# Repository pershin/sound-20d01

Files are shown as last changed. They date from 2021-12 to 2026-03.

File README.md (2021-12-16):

# Sound-20D01

## Sound-20D01MB

### Bill of Materials

| Reference | Value | Package | Qnty |
|:---:| --- | --- |:----:|
| C1, C2, C3, C4, C5, C10, C12, C13, C14, C16, C22, C25, C26, C28, C30, C42, C54 | 0.1uF, X7R, 50V | 1206 | 17 |
| C6, C7 | 15pF, C0G (NP0), 50V | 1206 | 2 |
| C8, C9 | 22pF, C0G (NP0), 50V | 1206 | 2 |
| C11, C41 | 1uF, X7R, 50V | 1206 | 2 |
| C15 | 4.7uF, X7R, 50V | 1206 | 1 |
| C18, C23 | 2.2nF, B32529C8222J000 | 2.5 x 6.5 x 7.3 | 2 |
| C19, C20, C33, C37, C40, C46, C47, C50, C51 | 2.2uF, X7R, 50V | 1206 | 9 |
| C21, C24, C45, C48, C49, C55, C17, C27 | 10uF, 16V | SMD 4 x 5.4 | 8 |
| C29, C43 | 470uF, 63V, B41851F8477M000 | 12.5 x 20 | 2 |
| C31 | 10uF, X7R, 50V | 1210 | 1 |
| C32, C39 | 4700uF, 35V | 18 x 35.5 | 2 |
| C34, C38 | 0.68uF | 7.2 x 4.5 mm | 2 |
| C35, C36 | 0.22uF, X7R, 50V | 1206 | 2 |
| C44 | 47uF, 16V | SMD 6.3 x 5.4 | 1 |
| C52 | 47uF, 50V | SMD 6.3 x 7.7 | 1 |
| C53 | 0.33uF, X7R, 50V | 1206 | 1 |
| D1, D4, D5 | KP-3216MGC (Green) | 1206 | 3 |
| D2 | KP-3216SEC (Orange) | 1206 | 1 |
| D3 | CRS04 | SOD-123F | 1 |
| F1 | MF-MSMF050-2 | 1812 (4532) | 1 |
| J1 | USBB-1J | USB-B1HSxx | 1 |
| J2 | X977B04 | 7.62 mm | 1 |
| J3 | PLD-16 | 2.54 mm | 1 |
| J4 | PLD-8 | 2.54 mm | 1 |
| J5, J13 | PLS-6 | 2.54 mm | 2 |
| J6, J7 | PLD-20 | 2.54 mm | 2 |
| J8, J9 | JST XH B02B-XH-A | 2.50 mm | 2 |
| J10 | JST VH B2P-VH | 3.96 mm | 1 |
| J11, J14, JP1, JP2 | PLS-3 | 2.54 mm | 4 |
| J12 | PLS-4 | 2.54 mm | 1 |
| L1, L2 | 22uH | Bourns SRR1260 | 2 |
| R1, R10, R17, R18, R22, R24 | 10K, 1% | 1206 | 6 |
| R2, R3, R15, R16 | 4.7K, 1% | 1206 | 4 |
| R4, R5, R8, R11, R12, R14 | 22R, 1% | 1206 | 6 |
| R6 | 390R, 1% | 1206 | 1 |
| R7 | 51R, 1% | 1206 | 1 |
| R9, R13 | 470R, 1% | 1206 | 2 |
| R19, R20, R21, R23, R26 | 1K, 1% | 1206 | 5 |
| R25 | 680R, 1% | 1206 | 1 |
| SW1 | DS1040-02RN | DIP SPSTx02 | 1 |
| U1 | USBLC6-2SC6 | SOT23-6L | 1 |
| U2 | STM32F446RCT6 | LQFP-64 | 1 |
| U3 | PCM5142PW | TSSOP-28 | 1 |
| U4 | TPA3123D2PWP | HTSSOP-24 (PWP0024B) | 1 |
| U5, U6 | FOD817B | DIP-4 7.62mm | 2 |
| U7, U8 | ADP3338AKCZ-3.3RL7 | SOT-223 | 2 |
| U9 | L7805ABD2T-TR | D2PAK (TO-263) | 1 |
| X1 | SM7745HEV-12.288M | 5 x 7 mm LCC Ceramic Package | 1 |
| Y1 | 32.768kHz (FC-135) | SMD 3215 | 1 |
| Y2 | 8MHz (AT-41CD2) | SMD HC49-SM | 1 |

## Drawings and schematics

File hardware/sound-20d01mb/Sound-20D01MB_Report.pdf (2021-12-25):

## Общий отчет о проекте

# Наименование: Sound-20D01MB

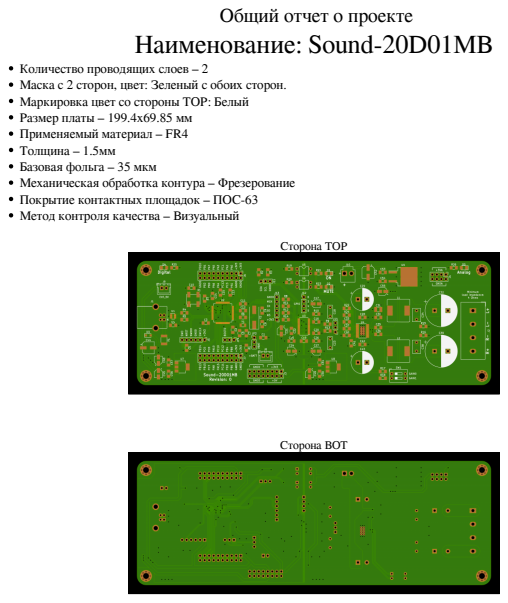
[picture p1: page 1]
Сторона TOP; Сторона BOT

Количество проводящих слоев – 2
Маска с 2 сторон, цвет: Зеленый с обоих сторон.
Маркировка цвет со стороны TOP: Белый
Размер платы – 199.4х69.85 мм
Применяемый материал – FR4
Толщина – 1.5мм
Базовая фольга – 35 мкм
Механическая обработка контура – Фрезерование
Покрытие контактных площадок – ПОС-63
Метод контроля качества – Визуальный

Powered by TCPDF (www.tcpdf.org)

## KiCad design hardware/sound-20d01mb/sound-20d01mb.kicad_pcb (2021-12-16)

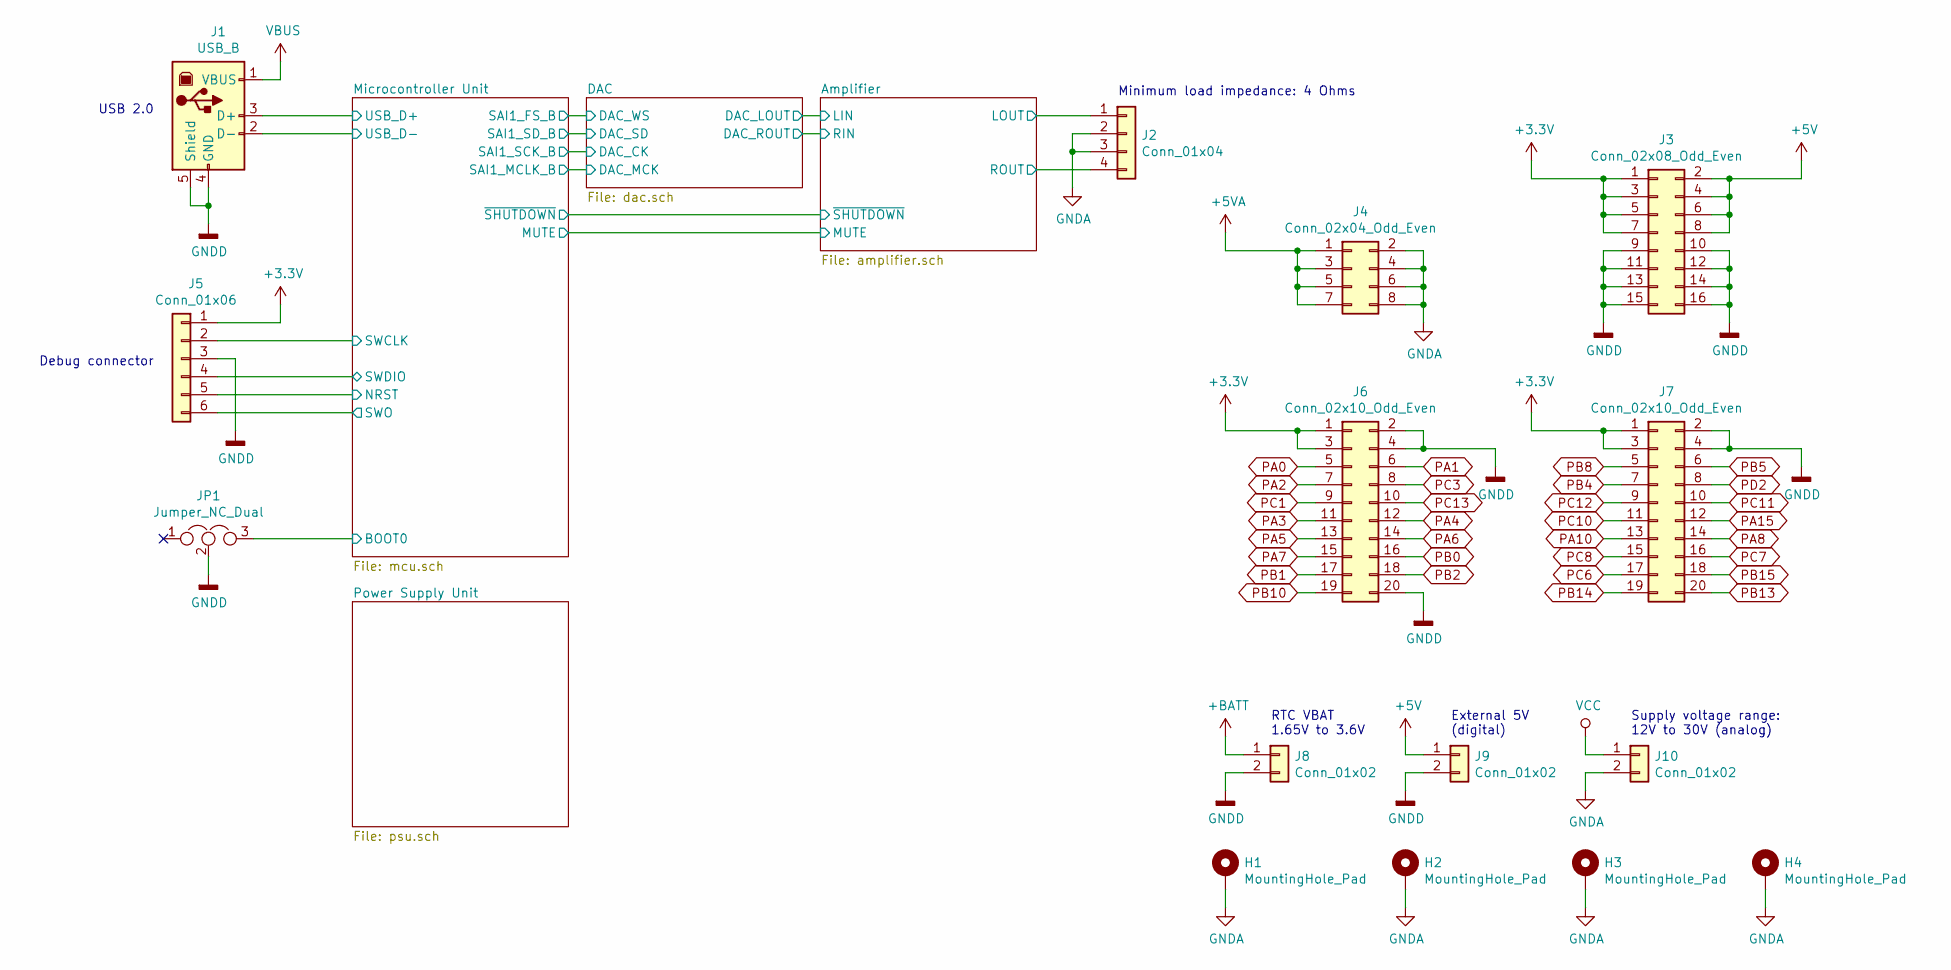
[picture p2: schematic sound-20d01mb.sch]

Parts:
H1, H2, H3, H4: MountingHole_Pad; MountingHole_3.2mm_M3_Pad_Via
J1: USB_B; USB_B_OST_USB-B1HSxx_Horizontal
J2: Conn_01x04; X977B04
J3: Conn_02x08_Odd_Even; PinHeader_2x08_P2.54mm_Vertical
J4: Conn_02x04_Odd_Even; PinHeader_2x04_P2.54mm_Vertical
J5: Conn_01x06; PinHeader_1x06_P2.54mm_Vertical
J6, J7: Conn_02x10_Odd_Even; PinHeader_2x10_P2.54mm_Vertical
J8, J9: Conn_01x02; JST_XH_B02B-XH-A_1x02_P2.50mm_Vertical
J10: Conn_01x02; JST_VH_B2P-VH_1x02_P3.96mm_Vertical
JP1: Jumper_NC_Dual; PinHeader_1x03_P2.54mm_Vertical

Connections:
+5V: J3.2, J3.4, J3.6, J3.8, J9.1; also elsewhere on the board
+5VA: J4.1, J4.3, J4.5, J4.7; also elsewhere on the board
+BATT: J8.1; also elsewhere on the board
/Amplifier/LOUT: J2.1; also elsewhere on the board
/Amplifier/ROUT: J2.4; also elsewhere on the board
/Microcontroller Unit/BOOT0: JP1.3; also elsewhere on the board
/Microcontroller Unit/NRST: J5.5; also elsewhere on the board
/Microcontroller Unit/SWCLK: J5.2; also elsewhere on the board
/Microcontroller Unit/SWDIO: J5.4; also elsewhere on the board
/Microcontroller Unit/SWO: J5.6; also elsewhere on the board
/Microcontroller Unit/USB_D+: J1.3 (D+); also elsewhere on the board
/Microcontroller Unit/USB_D-: J1.2 (D-); also elsewhere on the board
GNDA: H1.1, H2.1, H3.1, H4.1, J2.2, J2.3, J4.2, J4.4, J4.6, J4.8, J10.2; also elsewhere on the board
GNDD: J1.4 (GND), J1.5 (Shield), J3.9, J3.10, J3.11, J3.12, J3.13, J3.14, J3.15, J3.16, J5.3, J6.2, J6.4, J6.20, J7.2, J7.4, J8.2, J9.2, JP1.2; also elsewhere on the board
PA0: J6.5; also elsewhere on the board
PA1: J6.6; also elsewhere on the board
PA2: J6.7; also elsewhere on the board
PA3: J6.11; also elsewhere on the board
PA4: J6.12; also elsewhere on the board
PA5: J6.13; also elsewhere on the board
PA6: J6.14; also elsewhere on the board
PA7: J6.15; also elsewhere on the board
PA8: J7.14; also elsewhere on the board
PA10: J7.13; also elsewhere on the board
PA15: J7.12; also elsewhere on the board
PB0: J6.16; also elsewhere on the board
PB1: J6.17; also elsewhere on the board
PB2: J6.18; also elsewhere on the board
PB4: J7.7; also elsewhere on the board
PB5: J7.6; also elsewhere on the board
PB8: J7.5; also elsewhere on the board
PB10: J6.19; also elsewhere on the board
PB13: J7.20; also elsewhere on the board
PB14: J7.19; also elsewhere on the board
PB15: J7.18; also elsewhere on the board
PC1: J6.9; also elsewhere on the board
PC3: J6.8; also elsewhere on the board
PC6: J7.17; also elsewhere on the board
PC7: J7.16; also elsewhere on the board
PC8: J7.15; also elsewhere on the board
PC10: J7.11; also elsewhere on the board
PC11: J7.10; also elsewhere on the board
PC12: J7.9; also elsewhere on the board
PC13: J6.10; also elsewhere on the board
PD2: J7.8; also elsewhere on the board
VBUS: J1.1 (VBUS); also elsewhere on the board
VCC: J10.1; also elsewhere on the board

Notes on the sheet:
Minimum load impedance: 4 Ohms
Supply voltage range: 12V to 30V (analog)
Debug connector
USB 2.0
External 5V (digital)
RTC VBAT 1.65V to 3.6V

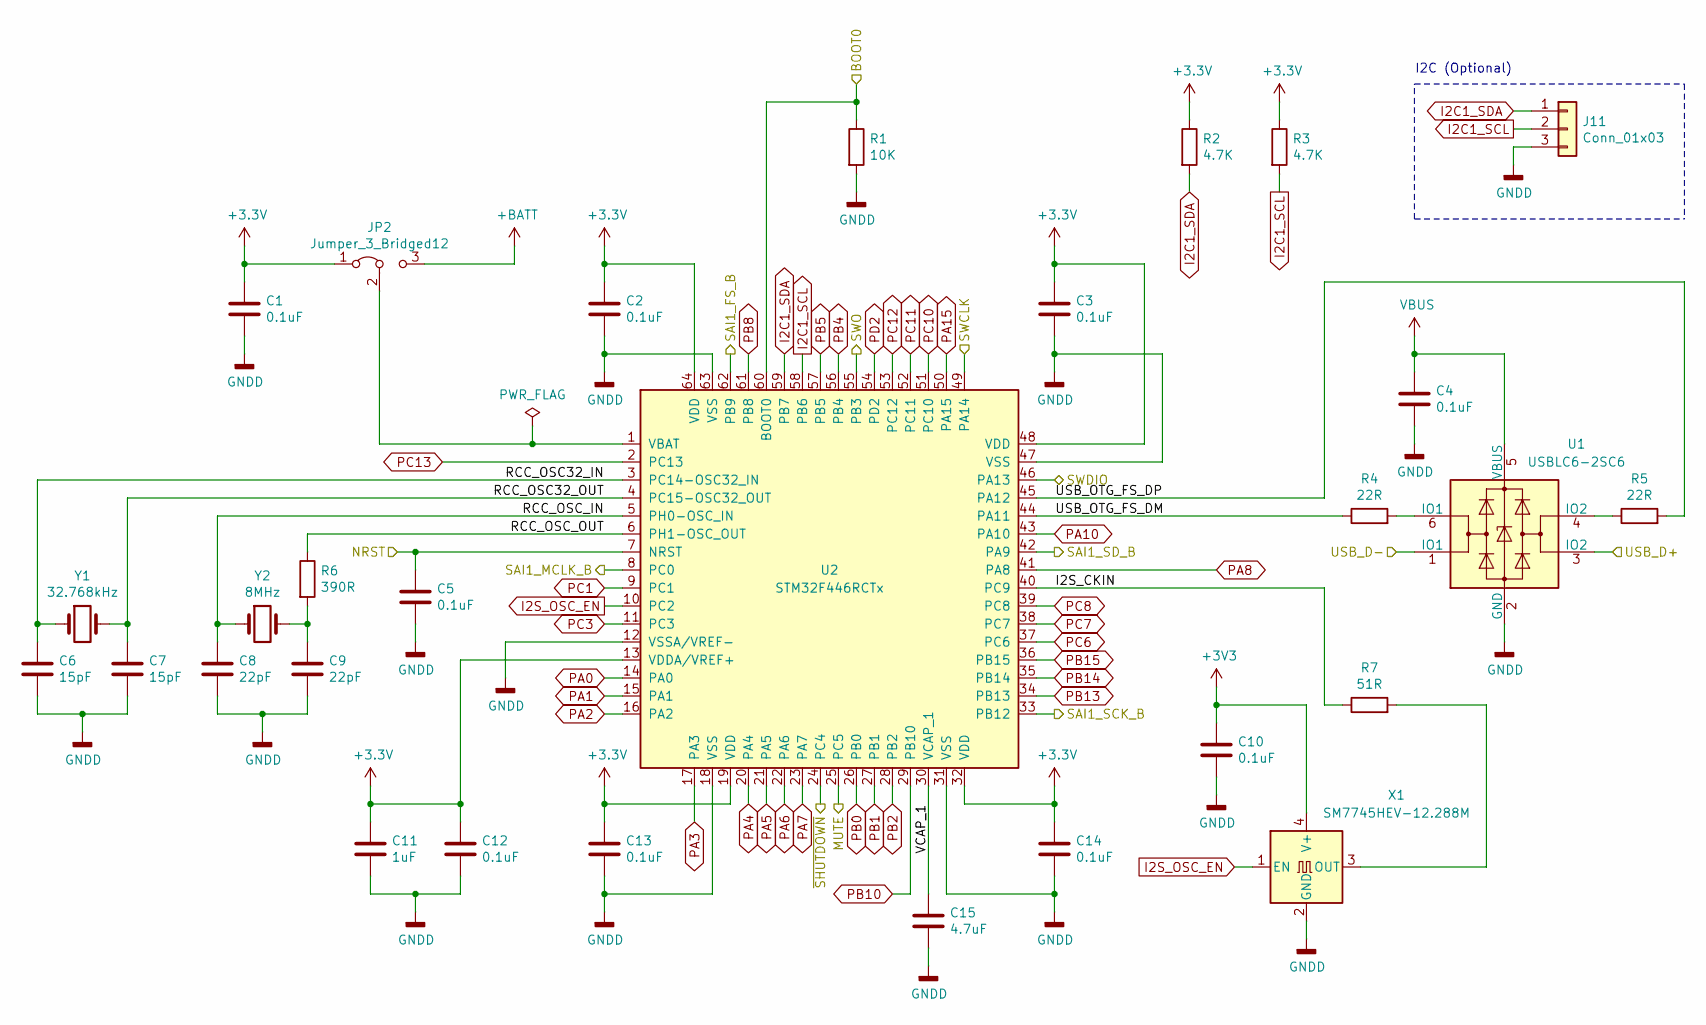
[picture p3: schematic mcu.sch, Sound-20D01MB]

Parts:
C1, C2, C3, C4, C5, C10, C12, C13, C14: 0.1uF; C_1206_3216Metric_Pad1.42x1.75mm_HandSolder
C6, C7: 15pF; C_1206_3216Metric_Pad1.42x1.75mm_HandSolder
C8, C9: 22pF; C_1206_3216Metric_Pad1.42x1.75mm_HandSolder
C11: 1uF; C_1206_3216Metric_Pad1.42x1.75mm_HandSolder
C15: 4.7uF; C_1206_3216Metric_Pad1.42x1.75mm_HandSolder
J11: Conn_01x03; PinHeader_1x03_P2.54mm_Vertical
JP2: Jumper_3_Bridged12; PinHeader_1x03_P2.54mm_Vertical
R1: 10K; R_1206_3216Metric_Pad1.42x1.75mm_HandSolder
R2, R3: 4.7K; R_1206_3216Metric_Pad1.42x1.75mm_HandSolder
R4, R5: 22R; R_1206_3216Metric_Pad1.42x1.75mm_HandSolder
R6: 390R; R_1206_3216Metric_Pad1.42x1.75mm_HandSolder
R7: 51R; R_1206_3216Metric_Pad1.42x1.75mm_HandSolder
U1: USBLC6-2SC6; SOT-23-6
U2: STM32F446RCTx; LQFP-64_10x10mm_P0.5mm
X1: SM7745HEV-12.288M; Oscillator_SMD_Fordahl_DFAS2-4Pin_7.3x5.1mm_HandSoldering
Y1: 32.768kHz; Crystal_SMD_3215-2Pin_3.2x1.5mm
Y2: 8MHz; Crystal_SMD_HC49-SD

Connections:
+BATT: JP2.3 (B); also elsewhere on the board
/Amplifier/MUTE: U2.25 (PC5); also elsewhere on the board
/Amplifier/~SHUTDOWN: U2.24 (PC4); also elsewhere on the board
/DAC/DAC_CK: U2.33 (PB12); also elsewhere on the board
/DAC/DAC_MCK: U2.8 (PC0); also elsewhere on the board
/DAC/DAC_SD: U2.42 (PA9); also elsewhere on the board
/DAC/DAC_WS: U2.62 (PB9); also elsewhere on the board
/Microcontroller Unit/BOOT0: R1.1, U2.60 (BOOT0); also elsewhere on the board
/Microcontroller Unit/I2S_CKIN: R7.1, U2.40 (PC9)
/Microcontroller Unit/NRST: C5.1, U2.7 (NRST); also elsewhere on the board
/Microcontroller Unit/RCC_OSC32_IN: C6.1, U2.3 (PC14-OSC32_IN), Y1.1
/Microcontroller Unit/RCC_OSC32_OUT: C7.1, U2.4 (PC15-OSC32_OUT), Y1.2
/Microcontroller Unit/RCC_OSC_IN: C8.1, U2.5 (PH0-OSC_IN), Y2.1
/Microcontroller Unit/RCC_OSC_OUT: R6.1, U2.6 (PH1-OSC_OUT)
/Microcontroller Unit/SWCLK: U2.49 (PA14); also elsewhere on the board
/Microcontroller Unit/SWDIO: U2.46 (PA13); also elsewhere on the board
/Microcontroller Unit/SWO: U2.55 (PB3); also elsewhere on the board
/Microcontroller Unit/USB_D+: U1.3 (IO2); also elsewhere on the board
/Microcontroller Unit/USB_D-: U1.1 (IO1); also elsewhere on the board
/Microcontroller Unit/USB_OTG_FS_DM: R4.1, U2.44 (PA11)
/Microcontroller Unit/USB_OTG_FS_DP: R5.2, U2.45 (PA12)
/Microcontroller Unit/VCAP_1: C15.1, U2.30 (VCAP_1)
GNDD: C1.2, C2.2, C3.2, C4.2, C5.2, C6.2, C7.2, C8.2, C9.2, C10.2, C11.2, C12.2, C13.2, C14.2, C15.2, J11.3, R1.2, U1.2 (GND), U2.12 (VSSA/VREF-), U2.18 (VSS), U2.31 (VSS), U2.47 (VSS), U2.63 (VSS), X1.2 (GND); also elsewhere on the board
I2C1_SCL: J11.2, R3.2, U2.58 (PB6); also elsewhere on the board
I2C1_SDA: J11.1, R2.2, U2.59 (PB7); also elsewhere on the board
I2S_OSC_EN: U2.10 (PC2), X1.1 (EN)
unnamed: C9.1, R6.2, Y2.2
unnamed: JP2.2 (C), U2.1 (VBAT)
unnamed: R4.2, U1.6 (IO1)
unnamed: R5.1, U1.4 (IO2)
unnamed: R7.2, X1.3 (OUT)
PA0: U2.14 (PA0); also elsewhere on the board
PA1: U2.15 (PA1); also elsewhere on the board
PA2: U2.16 (PA2); also elsewhere on the board
PA3: U2.17 (PA3); also elsewhere on the board
PA4: U2.20 (PA4); also elsewhere on the board
PA5: U2.21 (PA5); also elsewhere on the board
PA6: U2.22 (PA6); also elsewhere on the board
PA7: U2.23 (PA7); also elsewhere on the board
PA8: U2.41 (PA8); also elsewhere on the board
PA10: U2.43 (PA10); also elsewhere on the board
PA15: U2.50 (PA15); also elsewhere on the board
PB0: U2.26 (PB0); also elsewhere on the board
PB1: U2.27 (PB1); also elsewhere on the board
PB2: U2.28 (PB2); also elsewhere on the board
PB4: U2.56 (PB4); also elsewhere on the board
PB5: U2.57 (PB5); also elsewhere on the board
PB8: U2.61 (PB8); also elsewhere on the board
PB10: U2.29 (PB10); also elsewhere on the board
PB13: U2.34 (PB13); also elsewhere on the board
PB14: U2.35 (PB14); also elsewhere on the board
PB15: U2.36 (PB15); also elsewhere on the board
PC1: U2.9 (PC1); also elsewhere on the board
PC3: U2.11 (PC3); also elsewhere on the board
PC6: U2.37 (PC6); also elsewhere on the board
PC7: U2.38 (PC7); also elsewhere on the board
PC8: U2.39 (PC8); also elsewhere on the board
PC10: U2.51 (PC10); also elsewhere on the board
PC11: U2.52 (PC11); also elsewhere on the board
PC12: U2.53 (PC12); also elsewhere on the board
PC13: U2.2 (PC13); also elsewhere on the board
PD2: U2.54 (PD2); also elsewhere on the board
VBUS: C4.1, U1.5 (VBUS); also elsewhere on the board

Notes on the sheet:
I2C (Optional)

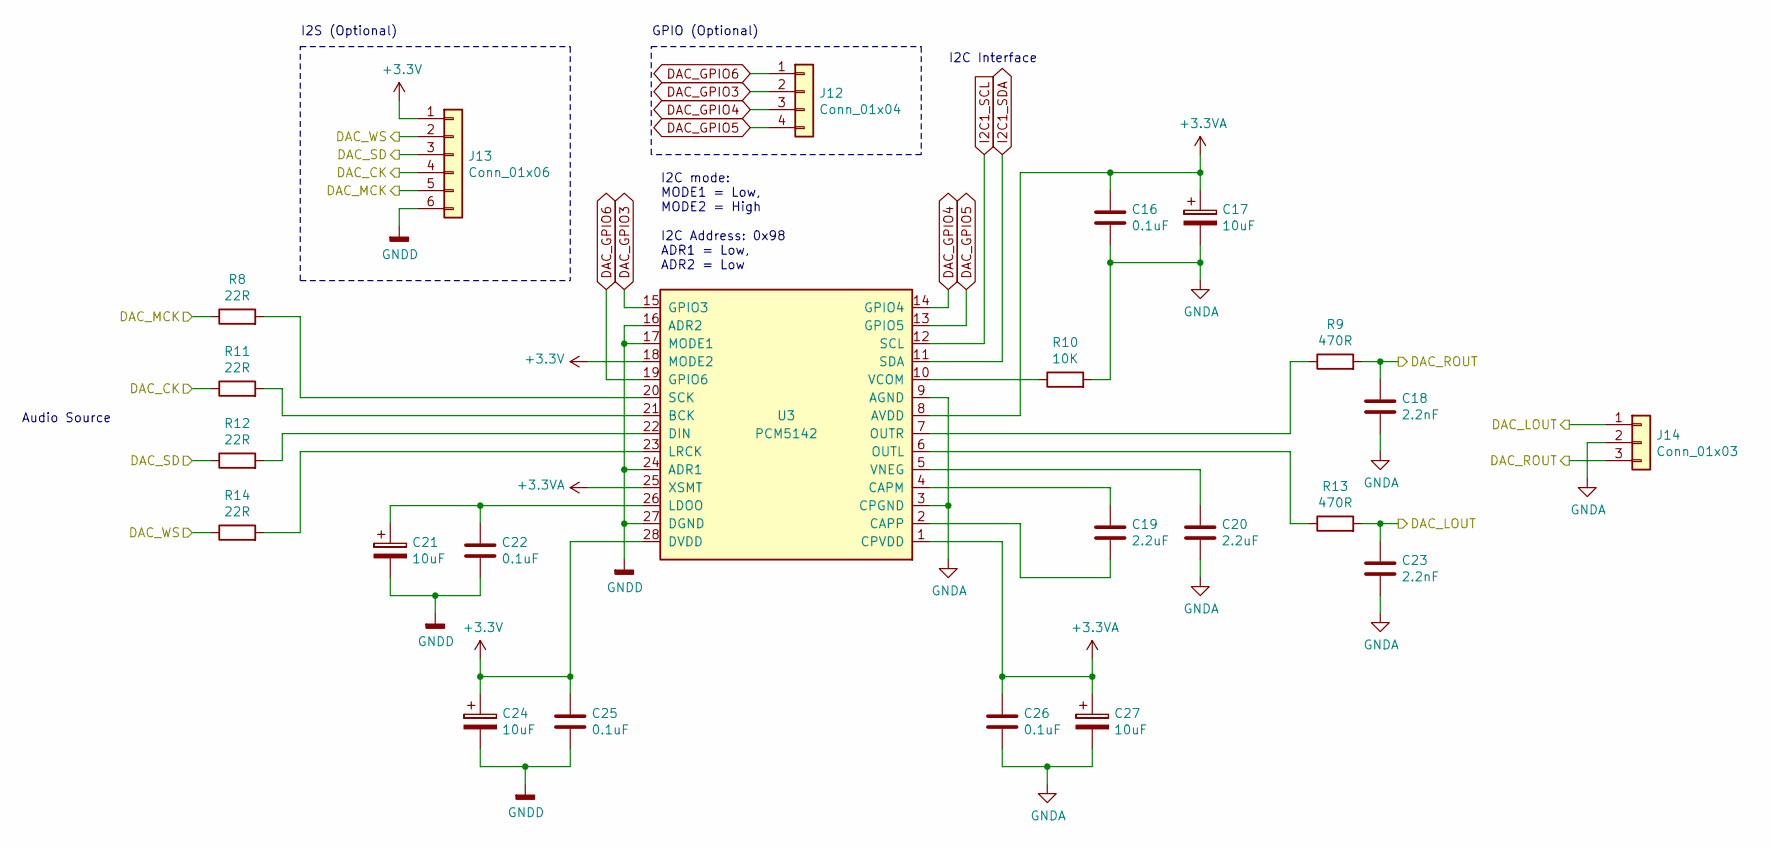
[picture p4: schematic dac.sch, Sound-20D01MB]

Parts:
C16, C22, C25, C26: 0.1uF; C_1206_3216Metric_Pad1.42x1.75mm_HandSolder
C17, C21, C24, C27: 10uF; CP_Elec_4x5.4
C18, C23: 2.2nF; C_Rect_L7.2mm_W2.5mm_P5.00mm_FKS2_FKP2_MKS2_MKP2
C19, C20: 2.2uF; C_1206_3216Metric_Pad1.42x1.75mm_HandSolder
J12: Conn_01x04; PinHeader_1x04_P2.54mm_Vertical
J13: Conn_01x06; PinHeader_1x06_P2.54mm_Vertical
J14: Conn_01x03; PinHeader_1x03_P2.54mm_Vertical
R8, R11, R12, R14: 22R; R_1206_3216Metric_Pad1.42x1.75mm_HandSolder
R9, R13: 470R; R_1206_3216Metric_Pad1.42x1.75mm_HandSolder
R10: 10K; R_1206_3216Metric_Pad1.42x1.75mm_HandSolder
U3: PCM5142; TSSOP-28_4.4x9.7mm_P0.65mm

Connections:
+3.3VA: C16.1, C17.1, C26.1, C27.1, U3.1 (CPVDD), U3.8 (AVDD), U3.25 (XSMT); also elsewhere on the board
/DAC/DAC_CK: J13.4, R11.1; also elsewhere on the board
/DAC/DAC_LOUT: C23.1, J14.1, R13.2; also elsewhere on the board
/DAC/DAC_MCK: J13.5, R8.1; also elsewhere on the board
/DAC/DAC_ROUT: C18.1, J14.3, R9.2; also elsewhere on the board
/DAC/DAC_SD: J13.3, R12.1; also elsewhere on the board
/DAC/DAC_WS: J13.2, R14.1; also elsewhere on the board
DAC_GPIO3: J12.2, U3.15 (GPIO3)
DAC_GPIO4: J12.3, U3.14 (GPIO4)
DAC_GPIO5: J12.4, U3.13 (GPIO5)
DAC_GPIO6: J12.1, U3.19 (GPIO6)
GNDA: C16.2, C17.2, C18.2, C20.2, C23.2, C26.2, C27.2, J14.2, R10.2, U3.3 (CPGND), U3.9 (AGND); also elsewhere on the board
GNDD: C21.2, C22.2, C24.2, C25.2, J13.6, U3.16 (ADR2), U3.17 (MODE1), U3.24 (ADR1), U3.27 (DGND); also elsewhere on the board
I2C1_SCL: U3.12 (SCL); also elsewhere on the board
I2C1_SDA: U3.11 (SDA); also elsewhere on the board
unnamed: C19.1, U3.4 (CAPM)
unnamed: C19.2, U3.2 (CAPP)
unnamed: C20.1, U3.5 (VNEG)
unnamed: C21.1, C22.1, U3.26 (LDOO)
unnamed: R8.2, U3.20 (SCK)
unnamed: R9.1, U3.7 (OUTR)
unnamed: R10.1, U3.10 (VCOM)
unnamed: R11.2, U3.21 (BCK)
unnamed: R12.2, U3.22 (DIN)
unnamed: R13.1, U3.6 (OUTL)
unnamed: R14.2, U3.23 (LRCK)

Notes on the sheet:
Audio Source
I2C Interface
I2C mode: MODE1 = Low, MODE2 = High I2C Address: 0x98 ADR1 = Low, ADR2 = Low
GPIO (Optional)
I2S (Optional)

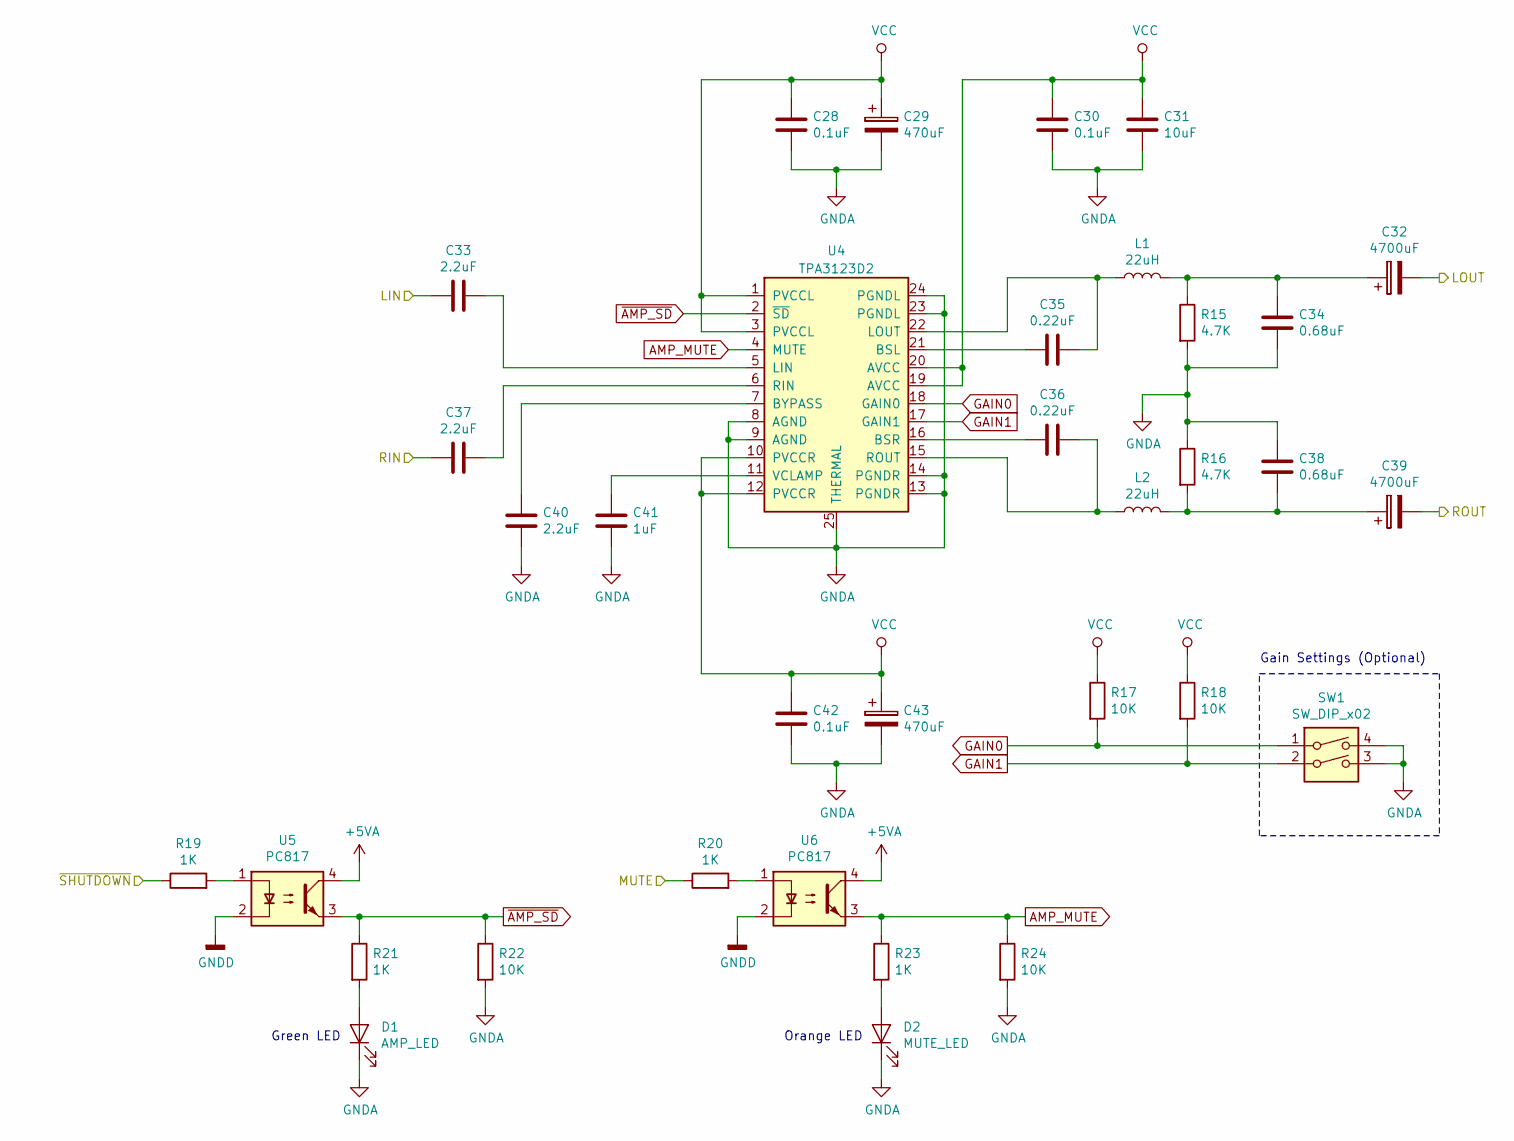
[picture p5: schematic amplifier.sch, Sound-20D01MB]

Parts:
C28, C30, C42: 0.1uF; C_1206_3216Metric_Pad1.42x1.75mm_HandSolder
C29, C43: 470uF; CP_Radial_D12.5mm_P5.00mm
C31: 10uF; C_1210_3225Metric_Pad1.42x2.65mm_HandSolder
C32, C39: 4700uF; CP_Radial_D18.0mm_P7.50mm
C33, C37, C40: 2.2uF; C_1206_3216Metric_Pad1.42x1.75mm_HandSolder
C34, C38: 0.68uF; C_Rect_L7.2mm_W4.5mm_P5.00mm_FKS2_FKP2_MKS2_MKP2
C35, C36: 0.22uF; C_1206_3216Metric_Pad1.42x1.75mm_HandSolder
C41: 1uF; C_1206_3216Metric_Pad1.42x1.75mm_HandSolder
D1: AMP_LED; LED_1206_3216Metric_Pad1.42x1.75mm_HandSolder
D2: MUTE_LED; LED_1206_3216Metric_Pad1.42x1.75mm_HandSolder
L1, L2: 22uH; L_Bourns_SRR1260
R15, R16: 4.7K; R_1206_3216Metric_Pad1.42x1.75mm_HandSolder
R17, R18, R22, R24: 10K; R_1206_3216Metric_Pad1.42x1.75mm_HandSolder
R19, R20, R21, R23: 1K; R_1206_3216Metric_Pad1.42x1.75mm_HandSolder
SW1: SW_DIP_x02; SW_DIP_SPSTx02_Slide_9.78x7.26mm_W7.62mm_P2.54mm
U4: TPA3123D2; PWP0024B
U5, U6: PC817; DIP-4_W7.62mm

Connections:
+5VA: U5.4, U6.4; also elsewhere on the board
/Amplifier/LOUT: C32.2; also elsewhere on the board
/Amplifier/MUTE: R20.1; also elsewhere on the board
/Amplifier/ROUT: C39.2; also elsewhere on the board
/Amplifier/~SHUTDOWN: R19.1; also elsewhere on the board
/DAC/DAC_LOUT: C33.1; also elsewhere on the board
/DAC/DAC_ROUT: C37.1; also elsewhere on the board
AMP_MUTE: R23.1, R24.1, U4.4 (MUTE), U6.3
GAIN0: R17.2, SW1.1, U4.18 (GAIN0)
GAIN1: R18.2, SW1.2, U4.17 (GAIN1)
GNDA: C28.2, C29.2, C30.2, C31.2, C34.2, C38.1, C40.2, C41.2, C42.2, C43.2, D1.1 (K), D2.1 (K), R15.2, R16.1, R22.2, R24.2, SW1.3, SW1.4, U4.8 (AGND), U4.9 (AGND), U4.13 (PGNDR), U4.14 (PGNDR), U4.23 (PGNDL), U4.24 (PGNDL), U4.25 (THERMAL); also elsewhere on the board
GNDD: U5.2, U6.2; also elsewhere on the board
unnamed: C32.1, C34.1, L1.2, R15.1
unnamed: C33.2, U4.5 (LIN)
unnamed: C35.1, U4.21 (BSL)
unnamed: C35.2, L1.1, U4.22 (LOUT)
unnamed: C36.1, U4.16 (BSR)
unnamed: C36.2, L2.1, U4.15 (ROUT)
unnamed: C37.2, U4.6 (RIN)
unnamed: C38.2, C39.1, L2.2, R16.2
unnamed: C40.1, U4.7 (BYPASS)
unnamed: C41.1, U4.11 (VCLAMP)
unnamed: D1.2 (A), R21.2
unnamed: D2.2 (A), R23.2
unnamed: R19.2, U5.1
unnamed: R20.2, U6.1
VCC: C28.1, C29.1, C30.1, C31.1, C42.1, C43.1, R17.1, R18.1, U4.1 (PVCCL), U4.3 (PVCCL), U4.10 (PVCCR), U4.12 (PVCCR), U4.19 (AVCC), U4.20 (AVCC); also elsewhere on the board
~AMP_SD: R21.1, R22.1, U4.2 (~SD), U5.3

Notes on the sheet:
Gain Settings (Optional)
Orange LED
Green LED

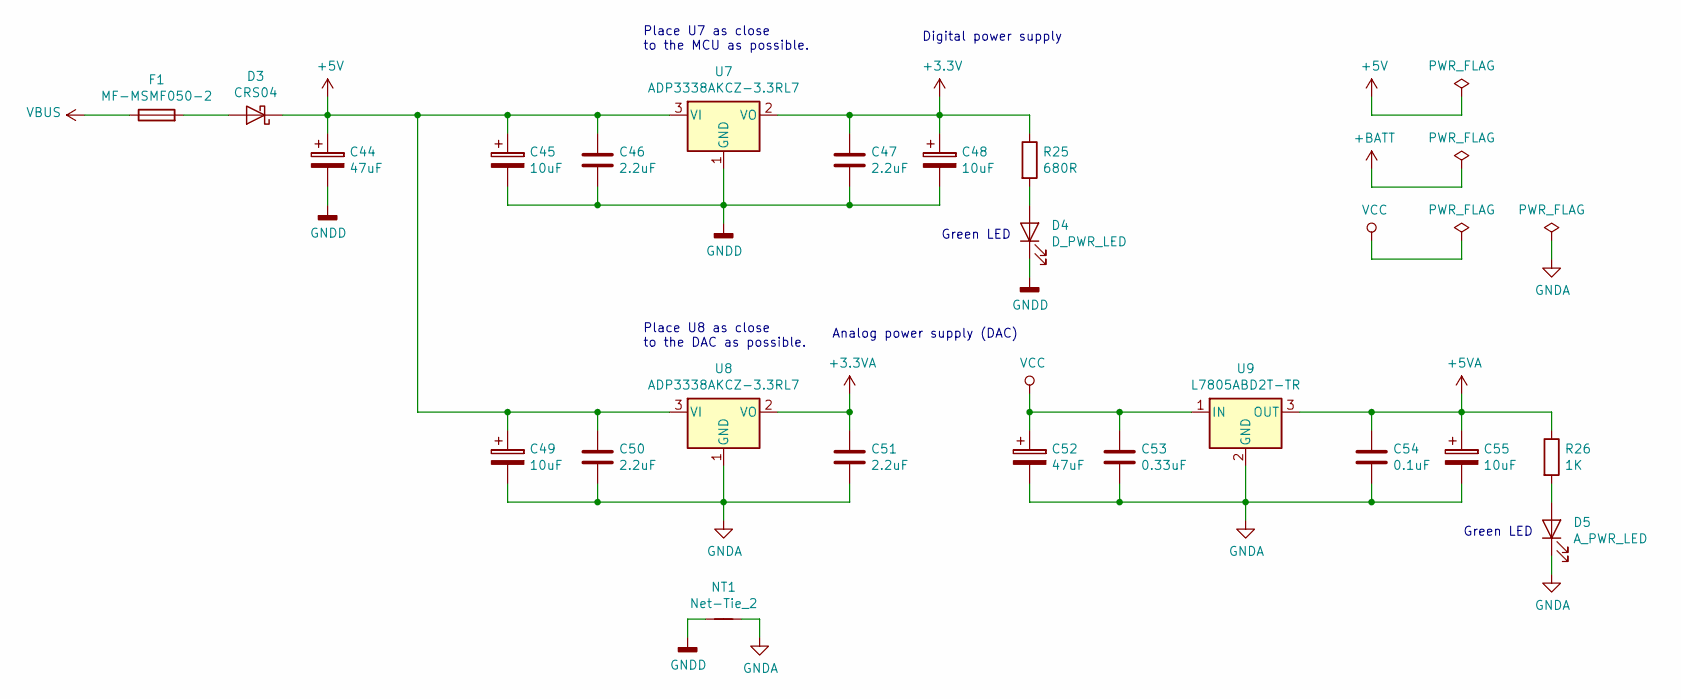
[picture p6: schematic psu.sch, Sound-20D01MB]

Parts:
C44: 47uF; CP_Elec_6.3x5.4
C45, C48, C49, C55: 10uF; CP_Elec_4x5.4
C46, C47, C50, C51: 2.2uF; C_1206_3216Metric_Pad1.42x1.75mm_HandSolder
C52: 47uF; CP_Elec_6.3x7.7
C53: 0.33uF; C_1206_3216Metric_Pad1.42x1.75mm_HandSolder
C54: 0.1uF; C_1206_3216Metric_Pad1.42x1.75mm_HandSolder
D3: CRS04; D_SOD-123F
D4: D_PWR_LED; LED_1206_3216Metric_Pad1.42x1.75mm_HandSolder
D5: A_PWR_LED; LED_1206_3216Metric_Pad1.42x1.75mm_HandSolder
F1: MF-MSMF050-2; Fuse_1812_4532Metric_Pad1.30x3.40mm_HandSolder
NT1: Net-Tie_2; NetTie-2_SMD_Pad2.0mm
R25: 680R; R_1206_3216Metric_Pad1.42x1.75mm_HandSolder
R26: 1K; R_1206_3216Metric_Pad1.42x1.75mm_HandSolder
U7, U8: ADP3338AKCZ-3.3RL7; SOT-223-3_TabPin2
U9: L7805ABD2T-TR; TO-263-2

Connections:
+3.3VA: C51.1, U8.2 (VO); also elsewhere on the board
+5V: C44.1, C45.1, C46.1, C49.1, C50.1, D3.1 (K), U7.3 (VI), U8.3 (VI); also elsewhere on the board
+5VA: C54.1, C55.1, R26.1, U9.3 (OUT); also elsewhere on the board
GNDA: C49.2, C50.2, C51.2, C52.2, C53.2, C54.2, C55.2, D5.1 (K), NT1.2, U8.1 (GND), U9.2 (GND); also elsewhere on the board
GNDD: C44.2, C45.2, C46.2, C47.2, C48.2, D4.1 (K), NT1.1, U7.1 (GND); also elsewhere on the board
unnamed: D3.2 (A), F1.2
unnamed: D4.2 (A), R25.2
unnamed: D5.2 (A), R26.2
VBUS: F1.1; also elsewhere on the board
VCC: C52.1, C53.1, U9.1 (IN); also elsewhere on the board

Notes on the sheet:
Analog power supply (DAC)
Digital power supply
Place U7 as close to the MCU as possible.
Place U8 as close to the DAC as possible.
Green LED

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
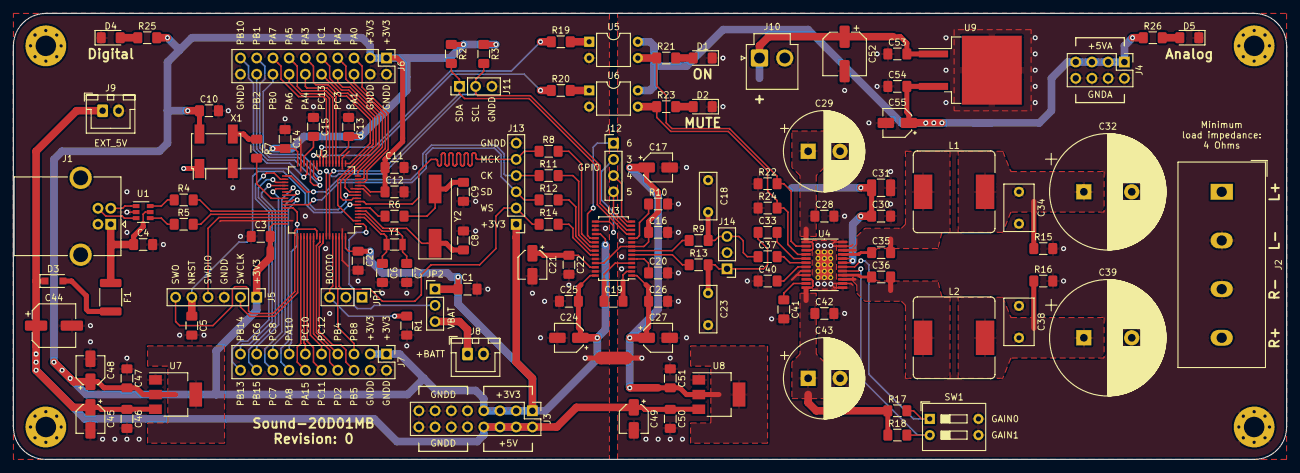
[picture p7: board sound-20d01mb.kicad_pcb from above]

Board: 2 copper layers, 199.4 x 69.8 mm, 123 parts (0 on the bottom side), 109 nets.

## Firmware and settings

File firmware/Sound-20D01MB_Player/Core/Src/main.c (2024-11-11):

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
/* Includes ------------------------------------------------------------------*/
#include "main.h"

/* USER CODE BEGIN Includes */
#include <string.h>
#include "audio.h"
#include "fs.h"
#include "display.h"
#include "playlist.h"

/* USER CODE END Includes */

/* USER CODE BEGIN PD */
#define DEFAULT_VOLUME 40
/* USER CODE END PD */

I2C_HandleTypeDef hi2c1;

SAI_HandleTypeDef hsai_BlockB1;
DMA_HandleTypeDef hdma_sai1_b;

SD_HandleTypeDef hsd;

SPI_HandleTypeDef hspi2;

/* USER CODE BEGIN PV */
volatile uint8_t read_next_chunk = 0;
volatile uint8_t *buffer_play = NULL;
volatile uint8_t *buffer_read = NULL;
uint8_t buffer_a[CLUSTER_SIZE];
uint8_t buffer_b[CLUSTER_SIZE];
volatile uint16_t numread;
volatile uint16_t cmd = 0;
volatile uint16_t track_number = 0;
volatile uint16_t old_track_number = 0;
volatile uint16_t number_of_tracks = 0;
volatile uint8_t volume = DEFAULT_VOLUME;
/* USER CODE END PV */

void SystemClock_Config(void);
static void MX_GPIO_Init(void);
static void MX_DMA_Init(void);
static void MX_SAI1_Init(void);
static void MX_I2C1_Init(void);
static void MX_SDIO_SD_Init(void);
static void MX_SPI2_Init(void);
/* USER CODE BEGIN 0 */
#ifdef DEBUG
int _write(int32_t file, uint8_t *ptr, int32_t len) {
	UNUSED(file);

	/* Implement your write code here, this is used by puts and printf for example */
	int i = 0;
	for (i = 0; i < len; i++)
		ITM_SendChar((*ptr++));
	return len;
}
#endif

int Player_Init(void) {
	BSP_AUDIO_Init(48000, volume, 0);
	BSP_Player_SetVolume(volume);
	return 0;
}

void HAL_GPIO_EXTI_Callback(uint16_t GPIO_Pin) {
	cmd = GPIO_Pin;
}

void HAL_SAI_TxCpltCallback(SAI_HandleTypeDef *hsai) {
	volatile uint8_t *temp;

	temp = buffer_play;
	buffer_play = buffer_read;
	buffer_read = temp;

	HAL_SAI_Transmit_DMA(&hsai_BlockB1, (uint8_t *) buffer_play, numread / 2);

	if (0 != track_number) {
		read_next_chunk = 1;
	}

	UNUSED(hsai);
}

void HAL_SAI_TxHalfCpltCallback(SAI_HandleTypeDef *hsai) {
	UNUSED(hsai);
}
/* USER CODE END 0 */

/**
  * @brief  The application entry point.
  * @retval int
  */
int main(void)
{
  /* MCU Configuration--------------------------------------------------------*/

  /* Reset of all peripherals, Initializes the Flash interface and the Systick. */
  HAL_Init();

  /* Configure the system clock */
  SystemClock_Config();

  /* Initialize all configured peripherals */
  MX_GPIO_Init();
  MX_DMA_Init();
  MX_SAI1_Init();
  MX_I2C1_Init();
  MX_SDIO_SD_Init();
  MX_SPI2_Init();
  /* USER CODE BEGIN 2 */
  Player_Init();

  number_of_tracks = fs_init();
  playlist_init(number_of_tracks);
  display_update(0);

  memset(buffer_a, 0, CLUSTER_SIZE);
  memset(buffer_b, 0, CLUSTER_SIZE);

  read_next_chunk = 0;
  buffer_play = buffer_a;
  buffer_read = buffer_b;
  numread = CLUSTER_SIZE;

  HAL_SAI_Transmit_DMA(&hsai_BlockB1, (uint8_t *) buffer_play, CLUSTER_SIZE / 2);

  /* USER CODE END 2 */

  /* Infinite loop */
  /* USER CODE BEGIN WHILE */
  while (1)
  {
		if (0 != cmd) {
			switch (cmd) {
				case VOL_D_Pin: /* Volume Down */
					if (0 < volume) {
						volume--;
						BSP_Player_SetVolume(volume);
					}
					break;
				case VOL_U_Pin: /* Volume Up */
					if (100 > volume) {
						volume++;
						BSP_Player_SetVolume(volume);
					}
					break;
				case PREV_Pin: /* Previous Track */
					track_number = playlist_prev();
					break;
				case NEXT_Pin: /* Next Track */
					track_number = playlist_next();
					break;
			}

			cmd = 0;
		}

		if (old_track_number != track_number) {
			old_track_number = track_number;

			display_update(track_number);

			while (1 != read_next_chunk) {}

			fs_open(track_number);
		}

		if (1 != read_next_chunk) {
			continue;
		}

		read_next_chunk = 0;

		numread = fs_read((uint8_t *) buffer_read);
		if (CLUSTER_SIZE != numread) {
			track_number = playlist_next();
		}

    /* USER CODE END WHILE */

    /* USER CODE BEGIN 3 */
  }
  /* USER CODE END 3 */
}

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


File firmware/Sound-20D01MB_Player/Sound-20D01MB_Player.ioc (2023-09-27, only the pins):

PH0-OSC_IN.Signal=RCC_OSC_IN
Mcu.UserName=STM32F446RCTx
PA6.GPIO_Label=VOL_U
PB6.Signal=I2C1_SCL
PB2.Signal=SDIO_CK
PC4.GPIO_Label=SHUTDOWN
PB7.Signal=I2C1_SDA
PB9.Signal=SAI1_FS_B
PB1.Signal=SDIO_D2
PA6.Signal=GPXTI6
PA2.GPIO_Label=PREV
PC5.Signal=GPIO_Output
PC2.GPIO_Label=I2S_OSC_EN
PA3.Signal=GPXTI3
PC11.Signal=SDIO_D3
PC8.Signal=SDIO_D0
PC4.Signal=GPIO_Output
PC2.Signal=GPIO_Output
PC0.Signal=SAI1_MCLK_B
PC14-OSC32_IN.Signal=RCC_OSC32_IN
PA0-WKUP.GPIO_Label=DISP_LATCH
PA0-WKUP.Signal=GPIO_Output
PA13.Signal=SYS_JTMS-SWDIO
PB8.GPIO_Label=SD_DETECT
PA9.Signal=SAI1_SD_B
PC15-OSC32_OUT.Signal=RCC_OSC32_OUT
PA1.Signal=GPIO_Output
PB10.Signal=SPI2_SCK
PA5.Signal=GPXTI5
PA1.GPIO_Label=DISP_EN
PH1-OSC_OUT.Signal=RCC_OSC_OUT
PA2.Signal=GPXTI2
PB3.Signal=SYS_JTDO-SWO
PA5.GPIO_Label=VOL_D
PC5.GPIO_Label=MUTE
PA14.Signal=SYS_JTCK-SWCLK
PB8.Signal=GPIO_Input
PC9.Signal=I2S_CKIN
PD2.Signal=SDIO_CMD
PB0.Signal=SDIO_D1
PC1.Signal=SPI2_MOSI
PB12.Signal=SAI1_SCK_B
PA3.GPIO_Label=NEXT

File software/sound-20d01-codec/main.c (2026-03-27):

/*
 * File:   main.c
 * Author: Sergey
 *
 * Created on October 29, 2023, 7:04 PM
 */

#include <stdio.h>
#include <stdlib.h>
#include <stdint.h>
#include <stdbool.h>
#include <getopt.h>
#include <signal.h>
#include <unistd.h>
#include "plac.h"
#include "encoder.h"
#include "decoder.h"
#include "player.h"
#include "wav.h"
#include "utils.h"

int verbose_flag = 0; /* Flag set by ‘--verbose’. */
int pcm_flag = 0;     /* Flag set by ‘--pcm’. */
volatile int stop_flag = 0;

static bool decode(char *, char *);
static bool encode(char *, char *);
static int play(char *);
static void usage(char *);
static void signal_handler(int);

int main(int argc, char **argv) {
    int c, option_index;
    char *src_filename, *dest_filename;
    static int encode_flag, decode_flag, play_flag;

    static struct option long_options[] = {
        {"verbose", no_argument, &verbose_flag, 1},
        {"encode", required_argument, &encode_flag, 1},
        {"decode", required_argument, &decode_flag, 1},
        {"pcm", no_argument, &pcm_flag, 1},
        {"play", required_argument, &play_flag, 1},
        {0, 0, 0, 0}};

    signal(SIGINT, signal_handler);
    signal(SIGTERM, signal_handler);

    dest_filename = NULL;

    for (;;) {
        option_index = 0;
        c = getopt_long(argc, argv, "o:", long_options, &option_index);

        /* Detect the end of the options. */
        if (c == -1) {
            break;
        }

        switch (c) {
            case 0:
                if (optarg) {
                    src_filename = optarg;
                }
                break;

            case 'o':
                dest_filename = optarg;
                break;

            case '?':
                break;

            default:
                abort();
        }
    }

    /* Print any remaining command line arguments (not options). */
    if (optind < argc) {
        printf("non-option ARGV-elements: ");
        while (optind < argc)
            printf("%s ", argv[optind++]);
        putchar('\n');
    }

    if (1 != encode_flag + decode_flag + play_flag) {
        usage(argv[0]);
        return EXIT_FAILURE;
    }

    if (encode_flag) {
        if (!encode(src_filename, dest_filename)) {
            return EXIT_FAILURE;
        }
    } else if (decode_flag) {
        if (!decode(src_filename, dest_filename)) {
            return EXIT_FAILURE;
        }
    }

    if (play_flag) {
        return play(src_filename);
    }

    return EXIT_SUCCESS;
}

static void signal_handler(int sig) {
    if (SIGINT == sig) {
        stop_flag = 1;
    }
}

static bool encode(char *src_filename, char *dest_filename) {
    FILE *src = NULL, *dest = NULL;
    WAVE_header *wav = NULL;
    int16_t *input = NULL;
    int i, numread, numwritten, best_mix_size, best_mix_num;
    long int src_size, dest_size;
    size_t bytes_left;
    bool result = false;

    input = malloc(PLAC_BUFSIZ * PLAC_NUM_CHANNELS * sizeof(int16_t));
    if (NULL == input) {
        fprintf(stderr, "Insufficient memory available\n");
        goto Cleanup;
    }

    src = fopen(src_filename, "r");
    if (NULL == src) {
        fprintf(stderr, "Cannot open file \"%s\"\n", src_filename);
        goto Cleanup;
    }

    wav = wav_header_read(src);
    if (NULL == wav) {
        fprintf(stderr, "Input file must be WAV format\n");
        goto Cleanup;
    }

    dest = fopen(dest_filename, "w");
    if (NULL == dest) {
        fprintf(stderr, "Cannot open file \"%s\"\n", dest_filename);
        goto Cleanup;
    }

    if (verbose_flag) {
        printf("Encoding...\n");
        printf("Input: %s\n", src_filename);
        printf("Output: %s\n", dest_filename);
    }

    dest_size = plac_header_write(dest);
    bytes_left = wav->data.Size;

    for (src_size = 0; bytes_left > 0;) {
        size_t to_read = PLAC_BUFSIZ * PLAC_NUM_CHANNELS * sizeof(int16_t);

        if (to_read > bytes_left) {
            to_read = bytes_left;
        }

        numread = fread(input, sizeof(uint8_t), to_read, src);
        if (0 == numread) {
            break;
        }

        bytes_left -= numread;
        best_mix_size = 0;
        best_mix_num = 0;

        for (i = 0; 5 > i; i++) {
            numwritten = encoder_encode(input, numread, i, NULL);

            if (0 == i) {
                best_mix_size = numwritten;
                best_mix_num = i;
            } else {
                if (best_mix_size > numwritten) {
                    best_mix_size = numwritten;
                    best_mix_num = i;
                }
            }
        }

        numwritten = encoder_encode(input, numread, best_mix_num, dest);

        src_size += numread;
        dest_size += numwritten;
    }

    if (verbose_flag) {
        printf("Input Size:  %ld\n", src_size);
        printf("Output Size: %ld\n", dest_size);
        printf("Delta:       %ld\n", dest_size - src_size);
    }

    result = true;

Cleanup:
    if (wav) {
        free(wav);
    }

    if (input) {
        free(input);
    }

    if (src) {
        fclose(src);
    }

    if (dest) {
        fclose(dest);
    }

    return result;
}
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

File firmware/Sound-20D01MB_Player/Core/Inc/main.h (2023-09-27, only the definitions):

#define I2S_OSC_EN_Pin GPIO_PIN_2
#define I2S_OSC_EN_GPIO_Port GPIOC
#define DISP_LATCH_Pin GPIO_PIN_0
#define DISP_LATCH_GPIO_Port GPIOA
#define DISP_EN_Pin GPIO_PIN_1
#define DISP_EN_GPIO_Port GPIOA
#define PREV_Pin GPIO_PIN_2
#define PREV_GPIO_Port GPIOA
#define PREV_EXTI_IRQn EXTI2_IRQn
#define NEXT_Pin GPIO_PIN_3
#define NEXT_GPIO_Port GPIOA
#define NEXT_EXTI_IRQn EXTI3_IRQn
#define VOL_D_Pin GPIO_PIN_5
#define VOL_D_GPIO_Port GPIOA
#define VOL_D_EXTI_IRQn EXTI9_5_IRQn
#define VOL_U_Pin GPIO_PIN_6
#define VOL_U_GPIO_Port GPIOA
#define VOL_U_EXTI_IRQn EXTI9_5_IRQn
#define SHUTDOWN_Pin GPIO_PIN_4
#define SHUTDOWN_GPIO_Port GPIOC
#define MUTE_Pin GPIO_PIN_5
#define MUTE_GPIO_Port GPIOC
#define SD_DETECT_Pin GPIO_PIN_8
#define SD_DETECT_GPIO_Port GPIOB

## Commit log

2021-07-01 Added new sheets (mcu.sch, dac.sch and amplifier.sch)
    [amplifier.sch, dac.sch, mcu.sch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]
2021-07-01 Added TPA3122D2
    [amplifier.sch]
2021-07-01 Updated amplifier schematic
    [amplifier.sch]
2021-07-02 Added PGA2311P
    [amplifier.sch]
2021-07-02 Added PCM5102A
    [dac.sch, sound-20d01mb.sch]
2021-07-02 Fixed -+VA
    [amplifier.sch]
2021-07-02 Added power supply unit
    [amplifier.sch, dac.sch, mcu.sch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]
2021-07-02 Updated power supply unit
    [psu.sch, sound-20d01mb.sch]
2021-07-02 Added STM32F446RCTx
    [mcu.sch]
2021-07-04 Updated MCU schematic
    [mcu.sch, sound-20d01mb.sch]
2021-07-04 Updated DAC
    [dac.sch]
2021-07-04 Added Gain Settings
    [amplifier.sch, psu.sch]
2021-07-04 Connected MCU to DAC
    [amplifier.sch, mcu.sch, sound-20d01mb.sch]
2021-07-04 Added Debug connector
    [sound-20d01mb.sch]
2021-07-04 Updated sound-20d01mb.sch
    [sound-20d01mb.sch]
2021-07-05 Added SWO
    [mcu.sch, sound-20d01mb.sch]
2021-07-05 Added OSC32
    [mcu.sch]
2021-07-05 Fixed mounting hole
    [sound-20d01mb.sch]
2021-07-06 Added ADG3304BRUZ
    [amplifier.sch]
2021-07-08 Updated amplifier.sch
    [amplifier.sch]
2021-07-09 Updated PSU
    [psu.sch, sound-20d01mb.sch]
2021-07-09 Updated text
    [sound-20d01mb.sch]
2021-07-10 Added LM27762
    [psu.sch]
2021-07-12 THT to SMD Capacitor
    [dac.sch]
2021-07-12 THT to SMD Capacitor (2)
    [amplifier.sch]
2021-07-15 Added PC817
    [amplifier.sch, sound-20d01mb.sch]
2021-08-29 Added oscillators sheet
    [amplifier.sch, dac.sch, mcu.sch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]
2021-08-29 Added AD1938
    [amplifier.sch, dac.sch, psu.sch]
2021-09-11 Updated schematics
    [amplifier.sch, dac.sch, psu.sch]
2021-09-12 Added SPI for Audio codec
2021-09-12 Added OSC
    [amplifier.sch, mcu.sch, oscillators.sch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]
2021-09-12 Added PCM5142
    [dac.sch]
2021-09-16 Added I2C Volume control
    [dac.sch, mcu.sch]
2021-09-18 New amplifier (TPA3123D2)
    [amplifier.sch]
2021-09-18 Updated PSU and DAC
    [dac.sch, psu.sch]
2021-09-19 Added X977B04
    [amplifier.sch, psu.sch, sound-20d01mb.sch]
2021-09-20 Added DAC GPIO
    [dac.sch]
2021-09-21 Updated schematic
    [amplifier.sch, mcu.sch, sound-20d01mb.sch]
2021-09-25 Added fuse for USB
    [psu.sch, sound-20d01mb.sch]
2021-09-25 Connected GNDD and GNDA
    [psu.sch]
2021-09-25 Updated mounting holes
    [sound-20d01mb.sch]
2021-09-25 Added USBLC6-2 Datasheet
    [mcu.sch]
2021-09-26 Updated fuse footprint
    [psu.sch]
2021-09-26 Added GPIO for MCU
    [mcu.sch, sound-20d01mb.sch]
2021-11-17 Added RTC-BAT
    [mcu.sch, sound-20d01mb.sch]
2021-11-19 Load capacitance for RTC Crystal
    [mcu.sch]
2021-11-19 Updated dac.sch
    [dac.sch]
2021-11-21 Added SD and MUTE to schematic
    [amplifier.sch]
2021-11-21 Added L7805
    [psu.sch]
2021-11-21 Added connector for +5VA
    [sound-20d01mb.sch]
2021-11-22 Added connector for I2C
    [mcu.sch, sound-20d01mb.sch]
2021-11-22 Removed oscillators.sch
    [amplifier.sch, dac.sch, mcu.sch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]
2021-11-22 Added datasheet for sm77h
    [mcu.sch]
2021-11-22 Removed SPI driver
2021-11-22 Fixed TPA3123D2
    [amplifier.sch]
2021-11-22 Fixed VCAP_1
    [dac.sch]
2021-11-23 PCM5142 I2C Mode
    [dac.sch]
2021-11-23 Annotate schematic
    [amplifier.sch, dac.sch, mcu.sch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]
2021-11-23 Updated: annotate schematic
    [amplifier.sch, dac.sch, mcu.sch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]
2021-11-25 Updated footprints
    [dac.sch]
2021-11-25 Updated PCB
    [sound-20d01mb.kicad_pcb]
2021-11-25 Updated C52 footprint
    [psu.sch, sound-20d01mb.kicad_pcb]
2021-11-29 Added PWP0024B
    [amplifier.sch, sound-20d01mb.kicad_pcb]
2021-11-30 Updated PWP0024B
    [sound-20d01mb.kicad_pcb]
2021-11-30 Added text EXT_5V
    [sound-20d01mb.kicad_pcb]
2021-12-01 All connections are connected
    [sound-20d01mb.kicad_pcb, sound-20d01mb.sch]
2021-12-02 New Gerber files
    [sound-20d01mb-B.Cu.gbr, sound-20d01mb-B.Mask.gbr, sound-20d01mb-B.Paste.gbr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]
2021-12-06 Added Bill of Materials
2021-12-16 Updated R25
    [psu.sch, sound-20d01mb.kicad_pcb]
2022-01-22 Added RTC Driver
2023-09-18 SPI to SDIO
2023-09-21 Added DMA SDIO
2023-09-27 Added display (SPI)
2023-11-10 Real SD device for FS

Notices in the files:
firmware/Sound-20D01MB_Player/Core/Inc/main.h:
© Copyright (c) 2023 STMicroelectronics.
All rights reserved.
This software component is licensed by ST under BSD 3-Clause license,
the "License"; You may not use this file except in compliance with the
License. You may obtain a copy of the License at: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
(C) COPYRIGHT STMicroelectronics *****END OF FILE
